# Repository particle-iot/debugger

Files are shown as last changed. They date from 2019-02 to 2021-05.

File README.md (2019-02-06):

# Particle debugger

**Design files for the CMSIS-DAP debugger**

The Particle Debugger gives you the power of professional debugging at a fraction of the cost. Using this accessory, you’ll be able to program Particle mesh-ready hardware over common interfaces like JTAG and SWD, using open source tools like GDB and openocd.

Supports the open source [CMSIS-DAP specification](https://os.mbed.com/handbook/DAPLink) and DAPLink firmware developed by ARM. On Mac, Linux, and Windows it requires no additional device drivers. 

It also provides a USB to TTL serial port. This requires no device drivers on Mac, Linux, or Windows 10 or later, but you may need to [install a device driver](https://os.mbed.com/docs/v5.9/tutorials/windows-serial-driver.html) for earlier versions of Windows to use the serial port feature.

Comes with one JTAG ribbon cable.

For more information about debugging see the [JTAG FAQ](https://docs.particle.io/support/particle-tools-faq/jtag/). Future version of Particle Workbench will support the Particle Debugger as well.

### Debugging mesh devices

Connecting a Argon, Boron, or Xenon to the debugger is as easy as connecting the included ribbon cable, as pictured below. It's keyed so it will only go in one way. The devices ship with a small plastic protective plug in the debugging connector; make sure you remove that first.

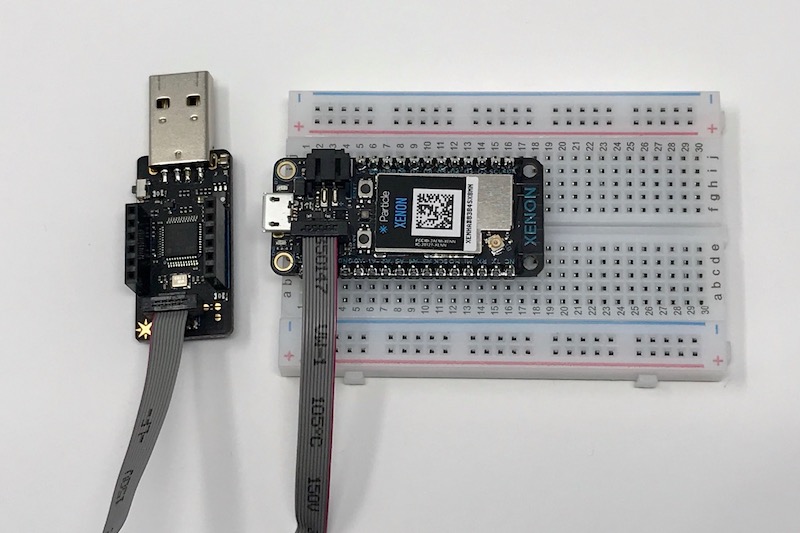
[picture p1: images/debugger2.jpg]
Debugger


### Debugging legacy platforms

Using the headers on the Particle Debugger you can attach it to other ARM processor devices like the STM32 in the Particle Photon, P1, Electron, and E Series for SWD (serial wire debug).

With the debugger positioned like this, USB connector toward you and the headers facing up:

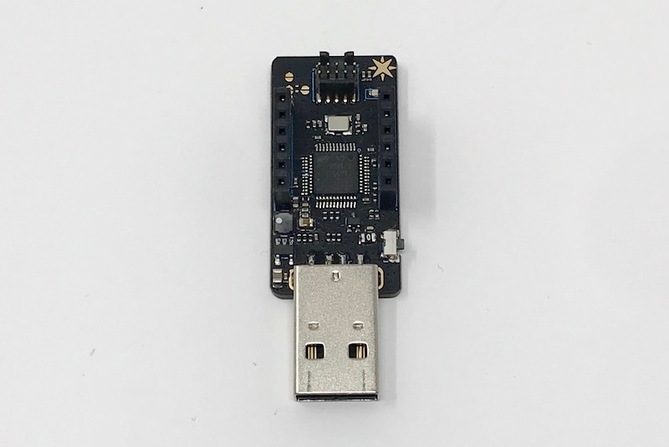
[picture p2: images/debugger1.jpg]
Debugger


| Left Header | Right Header |
| --- | ----- |
| VDD | SWCLK |
| RTS | SWDIO |
| RX  | NC |
| TX  | NC |  
| CTS | GND | 
| GND | VUSB  |

In order to use SWD debugging you need to connect:

- D7: SWDIO
- D6: SWCLK
- GND

## Connector

If you want to include the 5x2 micro JTAG connector on your own board a connector compatible with this one works:
 
- Connector Header Surface Mount 10 position 5x2 0.050" (1.27mm)
- [Samtec FTSH-105-01-F-DV-K](https://www.digikey.com/product-detail/en/FTSH-105-01-F-DV-K/SAM8796-ND/2649974)

In the connector directory is:

- JTAGConn.lbr, an Eagle CAD library file containing this connector footprint, symbol, and device. The device has all of the pins labeled for easy use.
- JTAGTest1.brd and .sch. This is just a simple breakout and is what I used to test the footprint. It works.

## Firmware Update

To update the interface firmware with the latest version:

1. Download the latest interface firmware from the firmware directory, above.
2. Press and hold the button on the Debugger.
3. Plug into an USB port of your PC.
4. It will show up a `MAINTENANCE` drive/volume.
5. Drag and drop the firmware to the drive/volume.
6. After that, it will be unmounted and remounted automatically and showing a `DAPLink` drive/volume.
7. Now, you can drag and drop any nRF52840 firmware into the `DAPLink` drive/volume to test.

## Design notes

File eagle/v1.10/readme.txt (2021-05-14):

2021/5/7
1.change U$1 to be closed so the RESET pin is actually connected to the debug port.
2.expose SWO and /RESET on the 2 empty breakout header pins.

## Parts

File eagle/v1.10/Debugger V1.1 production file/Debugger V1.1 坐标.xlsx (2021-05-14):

Name | X | Y | Degree | value | package
C1 | 4.41 | 13.75 | 180 | 0.1uF | C0402
C2 | 5.24 | 21.46 | 0 | 0.1uF | C0402
C3 | 4.41 | 24.86 | 270 | 0.1uF | C0402
C4 | -2.2 | 25.57 | 90 | 20pF | C0402
C5 | 3.4 | 26.55 | 270 | 20pF | C0402
C6 | -3.08 | 25.54 | 90 | 0.1uF | C0402
C7 | -2.55 | 23.45 | 180 | 0.1uF | C0402
C8 | -5.82 | 16.67 | 90 | 0.1uF | C0402
C9 | -4.04 | 10.06 | 0 | 22uF | C0805
C10 | -8.41 | 2.11 | 270 | 22uF | C0805
C11 | -4.43 | 12.22 | 0 | 0.1uF | C0402
C12 | -7.24 | 2.24 | 270 | 0.1uF | C0402
C13 | -4.39 | 11.35 | 0 | 470pF | C0402
C14 | -2.72 | 8.05 | 270 | 0.1uF | C0402
C15 | -4.42 | 13.11 | 0 | 1nF | C0402
C16 | 4.24 | 33.34 | 270 | 0.1uF | C0402
C17 | 5.12 | 33.35 | 270 | 0.1uF | C0402
C18 | 4.95 | 9.37 | 180 | 1nF | C0402
DEBUG_OUT | 0.13 | 32.07 | 180 | CON5X2 | CON5X2_1.27
F1 | 4.61 | 7.83 | 180 | ASMD0805-100 | F0805
F2 | -7.39 | 29.36 | 0 | ASMD0805-100 | F0805
K1 | 7.9 | 6.73 | 270 | K2-1806SQ | K2-1806C
L1 | -7.37 | 10.26 | 0 | NR3015T2R2M | INDUCTOR-NR3015
L2 | -5.84 | 13.36 | 90 | GZ1608D300TF | R-0603A
LED1 | 6.07 | 30.51 | 0 | LEDLED-0603 | LED-0603
Q1 | 2.57 | 10.4 | 0 | S9013W | SOT-323
R1 | -4.37 | 13.98 | 0 | 100R | R-0402S
R2 | -0.61 | 11.45 | 90 | 100R | R-0402S
R3 | -1.51 | 11.45 | 270 | 100R | R-0402S
R4 | 3.4 | 24.86 | 90 | 10K | R-0402S
R5 | -3.98 | 25.54 | 90 | 10K | R-0402S
R6 | 5.72 | 19.45 | 270 | 4.7K | R-0402S
R7 | -0.32 | 8.1 | 90 | 0R | R-0402S
R8 | 0.54 | 8.09 | 270 | 0R | R-0402S
R9 | 5.12 | 11.64 | 90 | 36K | R-0402S
R10 | 5.99 | 11.65 | 90 | 10K | R-0402S
R11 | -1.22 | 8.09 | 90 | 1.5K | R-0402S
R12 | 5.76 | 13.91 | 90 | 100R | R-0402S
R15 | 0.25 | 11.45 | 90 | 100R | R-0402S
R16 | 5.74 | 15.87 | 90 | 1K | R-0402S
R17 | -5.63 | 31.29 | 270 | 100R | R-0402S
R18 | -5.33 | 8.08 | 90 | 560K | R-0402S
R19 | -4.5 | 8.08 | 270 | 124K | R-0402S
R20 | -3.66 | 8.05 | 270 | 10K | R-0402S
U1 | 0 | 17.83 | 270 | GD32F103CBT6 | LQFP-48-7X7
U2 | -7.42 | 6.07 | 180 | SY8088AAC | SOT23-5L
USB1 | -0.01 | 4.37 | 0 | USB_PCB | USB_PCB
Y1 | 0.51 | 25.59 | 0 | 16Mhz 9PF | CRY_3225_SMT

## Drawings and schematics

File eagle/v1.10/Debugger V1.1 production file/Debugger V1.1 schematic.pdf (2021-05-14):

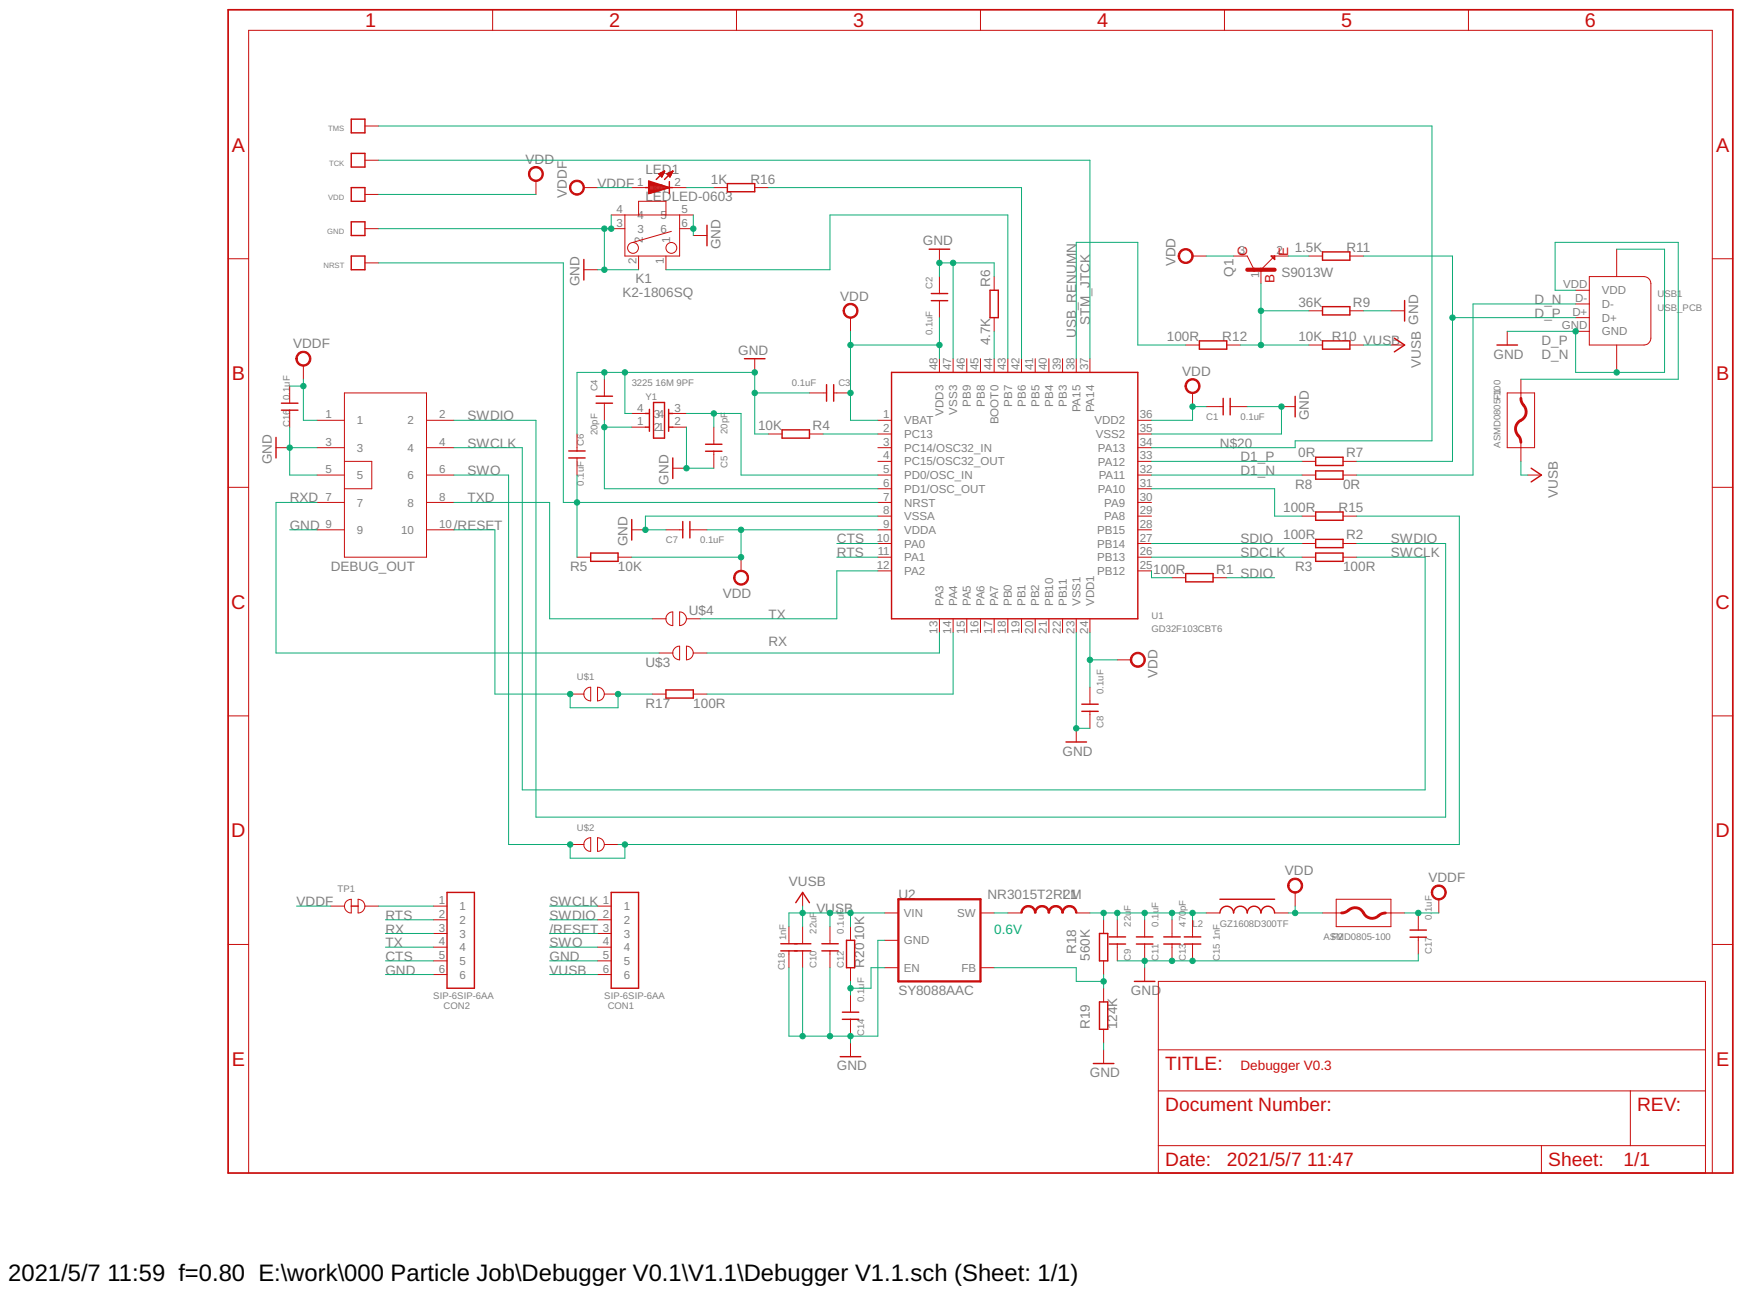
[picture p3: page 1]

2 LED1

2021/5/7 11:59 f=0.80 E:\work\000 Particle Job\Debugger V0.1\V1.1\Debugger V1.1.sch (Sheet: 1/1)

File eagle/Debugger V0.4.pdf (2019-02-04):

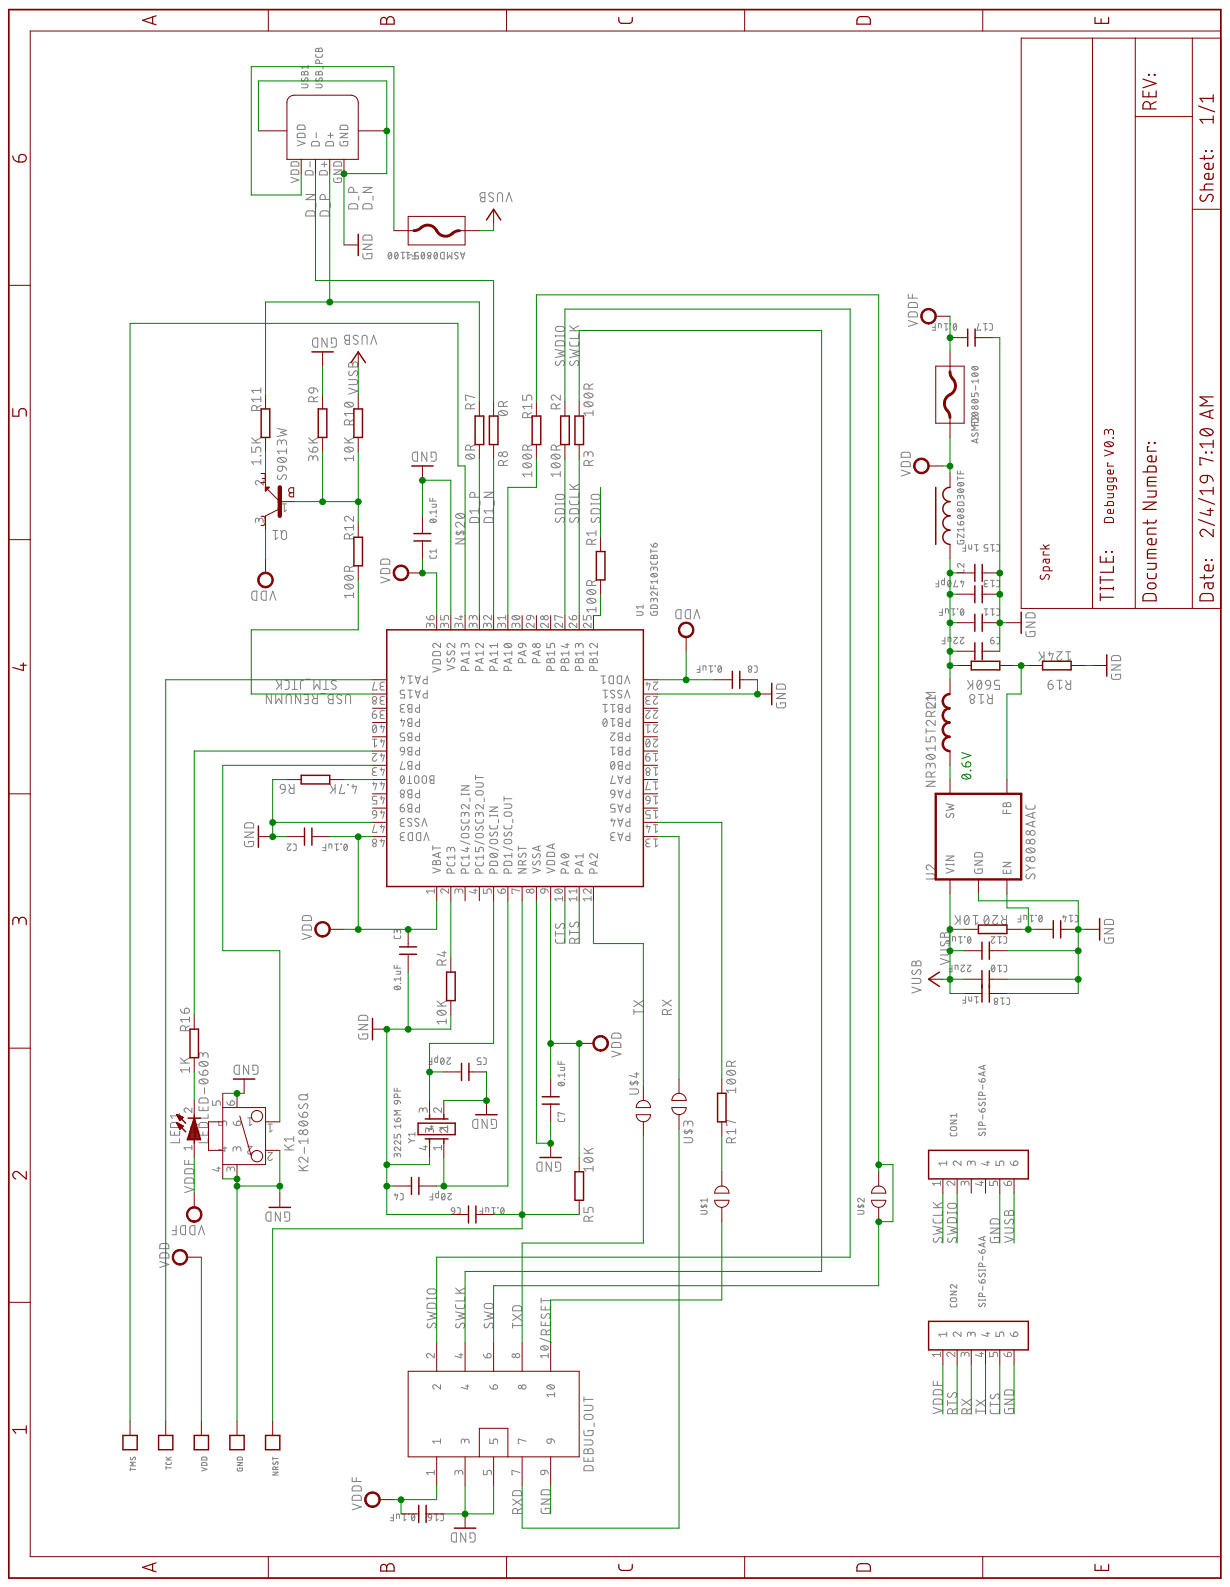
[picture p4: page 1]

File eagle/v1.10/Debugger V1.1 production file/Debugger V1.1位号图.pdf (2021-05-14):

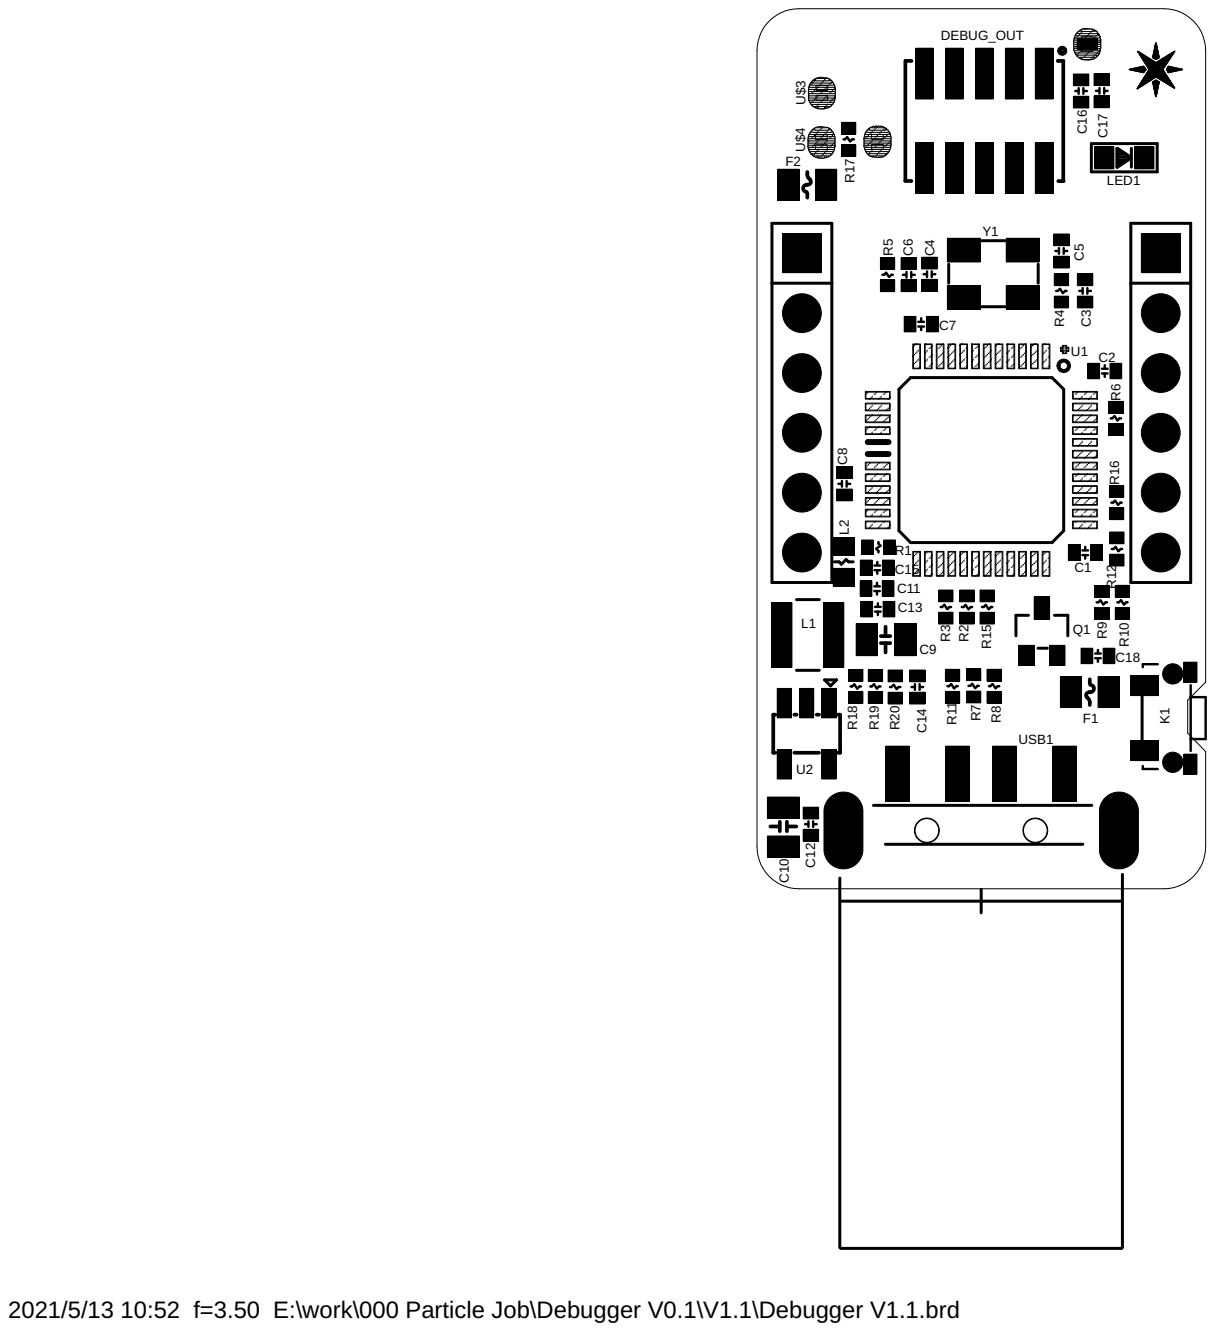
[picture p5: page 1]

2021/5/13 10:52 f=3.50 E:\work\000 Particle Job\Debugger V0.1\V1.1\Debugger V1.1.brd

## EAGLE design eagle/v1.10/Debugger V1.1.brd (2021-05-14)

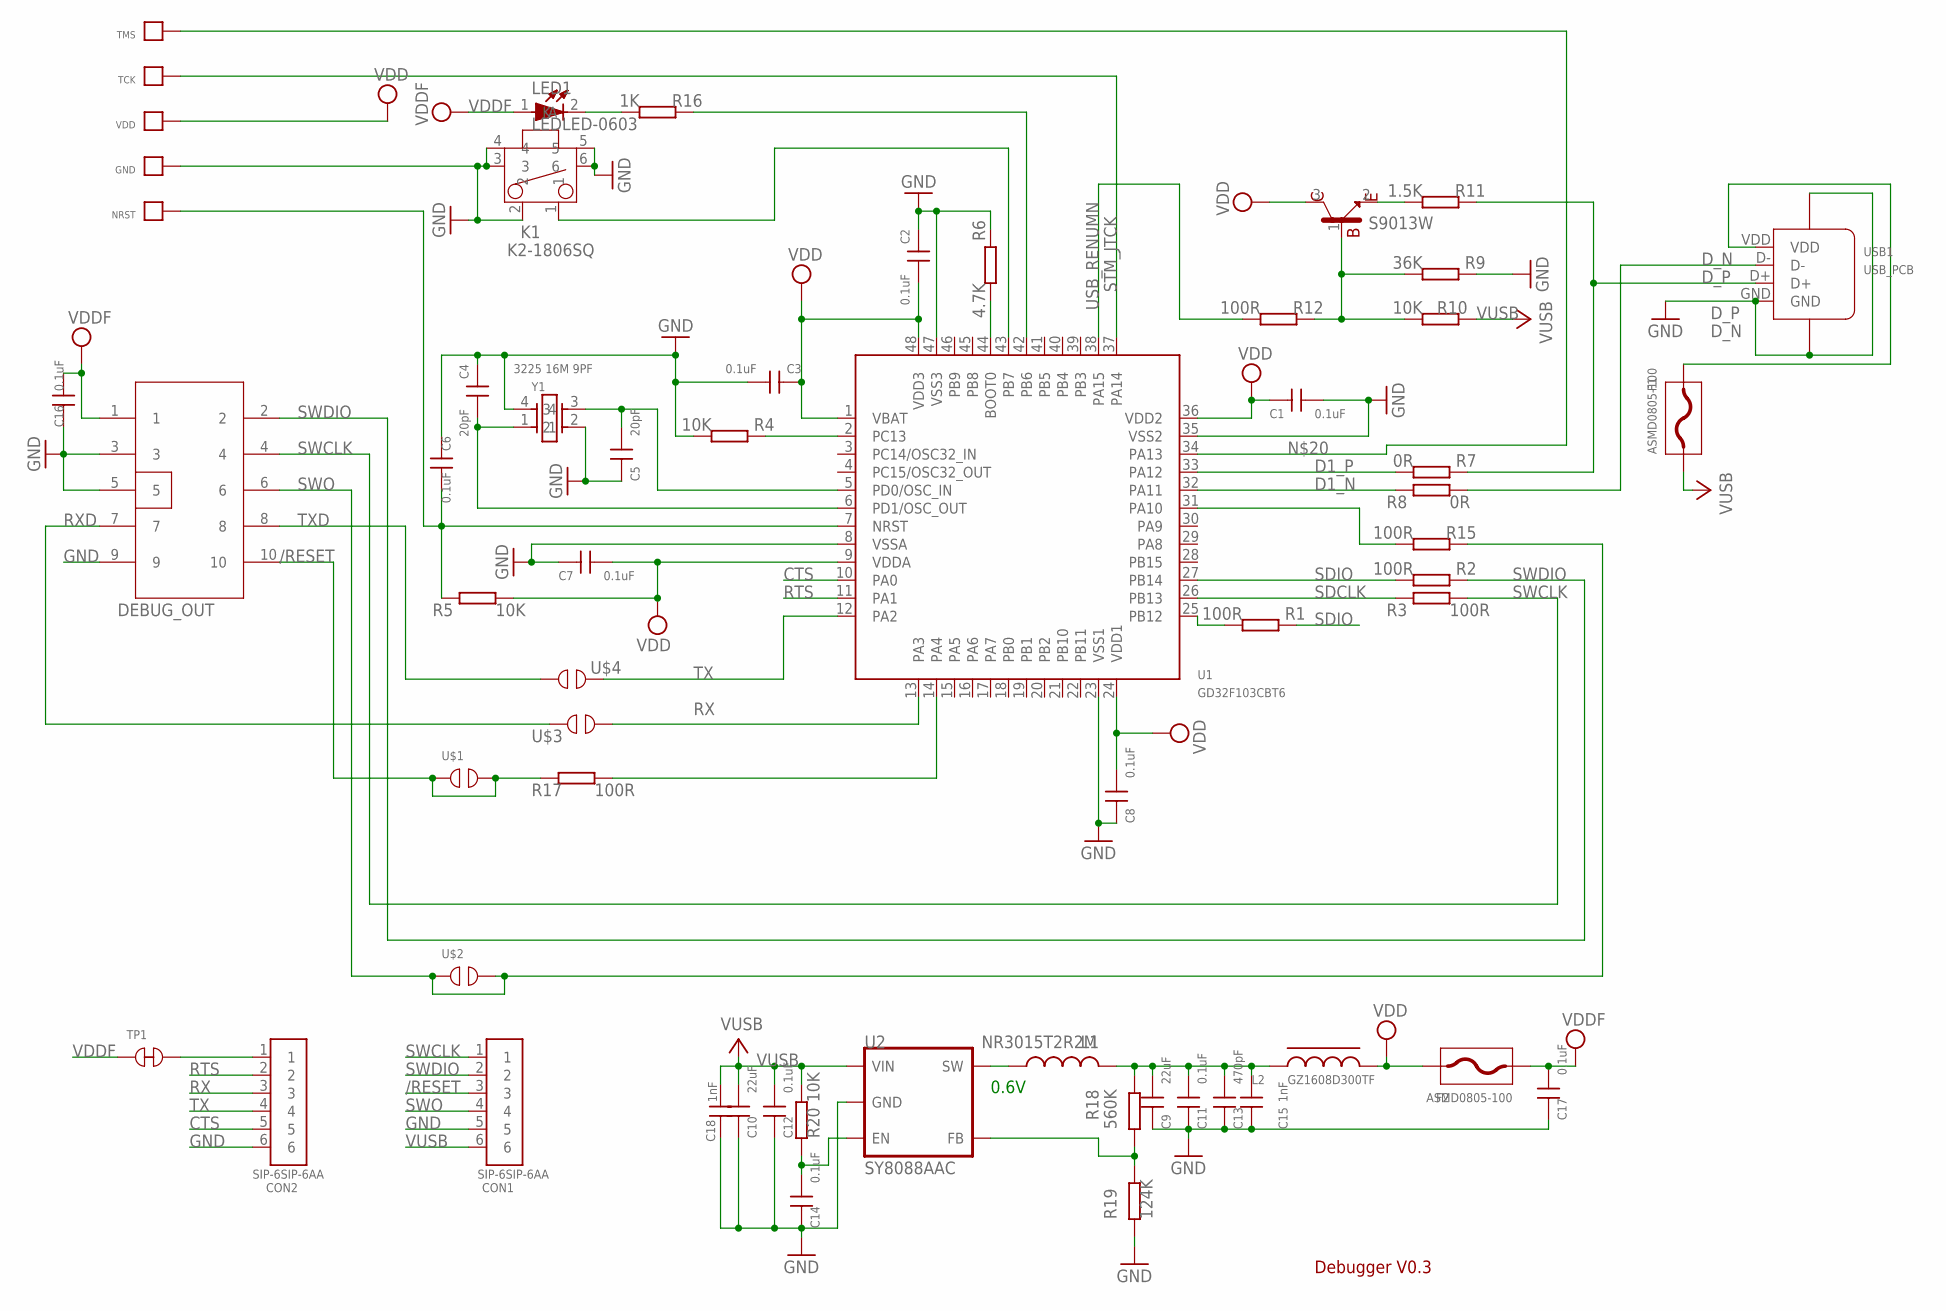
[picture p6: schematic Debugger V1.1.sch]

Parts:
C1, C2, C3, C6, C7, C8, C11, C12, C14, C16, C17: 0.1uF; C0402
C4, C5: 20pF; C0402
C9, C10: 22uF; C0805
C13: 470pF; C0402
C15, C18: 1nF; C0402
CON1, CON2: SIP-6SIP-6AA; PAIZHEN6P_2.54AA
DEBUG_OUT: CON5X2; CON5X2_1.27
F1, F2: ASMD0805-100; F0805
GND: TPTP; TP
K1: K2-1806SQ; K2-1806C
L1: NR3015T2R2M; INDUCTOR-NR3015
L2: GZ1608D300TF; R-0603A
LED1: LEDLED-0603; LED-0603
NRST: TPTP; TP
Q1: S9013W; SOT-323
R1, R2, R3, R12, R15, R17: 100R; R-0402S
R4, R5, R10, R20: 10K; R-0402S
R6: 4.7K; R-0402S
R7, R8: 0R; R-0402S
R9: 36K; R-0402S
R11: 1.5K; R-0402S
R16: 1K; R-0402S
R18: 560K; R-0402S
R19: 124K; R-0402S
TCK: TPTP; TP
TMS: TPTP; TP
TP1: TP_SHORT
U1: GD32F103CBT6; LQFP-48-7X7
U2: SY8088AAC; SOT23-5L
U$1, U$2, U$3, U$4: TP_OPEN
USB1: USB_PCB
VDD: TPTP; TP
Y1: 3225 16M 9PF; CRY_3225_SMT

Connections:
/RESET: CON1.3, DEBUG_OUT.10, R17.1, U$1.1, U$1.2
CTS: CON2.5, U1.10 (PA0)
D1_N: R8.1, U1.32 (PA11)
D1_P: R7.2, U1.33 (PA12)
D_N: R8.2, USB1.D-
D_P: R7.1, R11.1, USB1.D+
GND: C1.1, C2.2, C3.1, C4.2, C5.2, C6.2, C7.2, C8.2, C9.2, C10.2, C11.2, C12.2, C13.2, C14.2, C15.2, C16.2, C17.2, C18.2, CON1.5, CON2.6, DEBUG_OUT.3, DEBUG_OUT.5, DEBUG_OUT.9, GND.P$1, K1.2, K1.3, K1.4, K1.5, K1.6, R4.2, R6.1, R9.1, R19.1, U1.8 (VSSA), U1.23 (VSS1), U1.35 (VSS2), U1.47 (VSS3), U2.2 (GND), USB1.GND, USB1.GND1, USB1.GND2, Y1.2, Y1.4
unnamed: R1.2, U1.25 (PB12)
unnamed: C6.1, NRST.P$1, R5.1, U1.7 (NRST)
unnamed: R4.1, U1.2 (PC13)
unnamed: C5.1, U1.5 (PD0/OSC_IN), Y1.3
unnamed: C4.1, U1.6 (PD1/OSC_OUT), Y1.1
unnamed: Q1.1 (B), R9.2, R10.2, R12.1
unnamed: R15.2, U1.31 (PA10)
unnamed: Q1.2 (E), R11.2
unnamed: R6.2, U1.44 (BOOT0)
unnamed: LED1.2 (K), R16.2
unnamed: F1.P$2 (2), USB1.VDD
unnamed: K1.1, U1.43 (PB7)
unnamed: R16.1, U1.42 (PB6)
unnamed: L1.1, U2.3 (SW)
unnamed: R17.2, U1.14 (PA4)
unnamed: TMS.P$1, U1.34 (PA13)
unnamed: R18.1, R19.2, U2.5 (FB)
unnamed: C14.1, R20.1, U2.1 (EN)
unnamed: C9.1, C11.1, C13.1, C15.1, L1.2, L2.1, R18.2
RTS: CON2.2, U1.11 (PA1)
RX: CON2.3, U1.13 (PA3), U$3.2
RXD: DEBUG_OUT.7, U$3.1
SDCLK: R3.1, U1.26 (PB13)
SDIO: R1.1, R2.2, U1.27 (PB14)
STM_JTCK: TCK.P$1, U1.37 (PA14)
SWCLK: CON1.1, DEBUG_OUT.4, R3.2
SWDIO: CON1.2, DEBUG_OUT.2, R2.1
SWO: CON1.4, DEBUG_OUT.6, R15.1, U$2.1, U$2.2
TX: CON2.4, U1.12 (PA2), U$4.1
TXD: DEBUG_OUT.8, U$4.2
USB_RENUMN: R12.2, U1.38 (PA15)
VDD: C1.2, C2.1, C3.2, C7.1, C8.1, F2.P$2 (2), L2.2, Q1.3 (C), R5.2, U1.1 (VBAT), U1.9 (VDDA), U1.24 (VDD1), U1.36 (VDD2), U1.48 (VDD3), VDD.P$1
VDDF: C16.1, C17.1, CON2.1, DEBUG_OUT.1, F2.P$1 (1), LED1.1 (A), TP1.1, TP1.2
VUSB: C10.1, C12.1, C18.1, CON1.6, F1.P$1 (1), R10.1, R20.2, U2.4 (VIN)

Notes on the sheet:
0.6V
Debugger V0.3

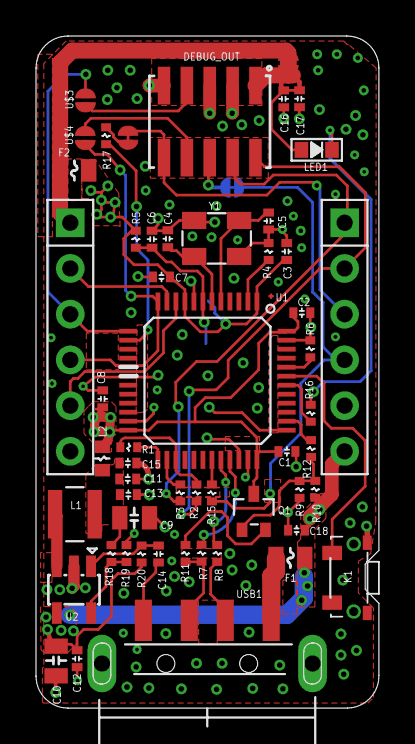
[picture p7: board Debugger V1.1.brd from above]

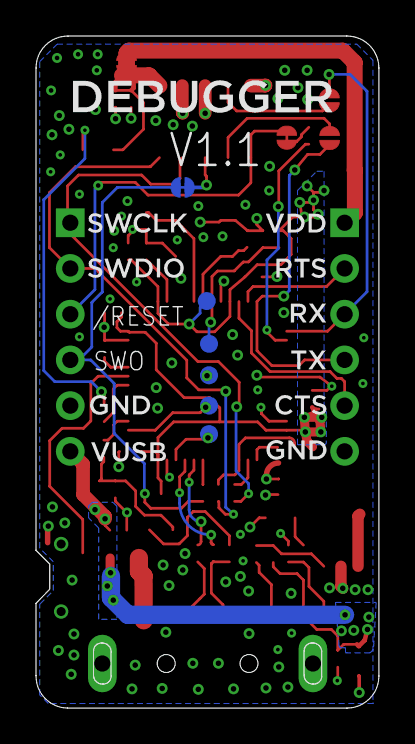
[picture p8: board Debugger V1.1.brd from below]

Board: 2 copper layers, 19.0 x 37.3 mm, 62 parts (7 on the bottom side), 41 nets.

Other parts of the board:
U$5, U$6: SPARK_LOGO2

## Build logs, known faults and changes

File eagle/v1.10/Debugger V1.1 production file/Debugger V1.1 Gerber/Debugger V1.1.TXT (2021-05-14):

%
M48
M72
T01C0.00787
T02C0.00800
T03C0.01000
T04C0.01200
T05C0.01969
T06C0.03543
T07C0.03937
%
T01
X67150Y187713
T02
X72550Y182313
X74650Y178613
X68350Y173713
X60950Y162013
X59150Y168913
X56750Y166013
X55850Y154513
X61650Y150813
X68350Y142513
X48650Y111813
X46450Y108413
X44350Y110713
X34650Y103713
X33150Y99313
X32550Y93513
X31350Y108213
X24350Y99513
X21950Y77713
X24950Y74113
X11950Y67313
X28650Y127113
X29350Y130913
X27350Y144013
X13150Y131713
X6350Y132313
X6150Y142313
X46950Y163713
T03
X42350Y171113
X41250Y164313
X37050Y164513
X32050Y171413
X26850Y174513
X54050Y108213
X57950Y104113
X39550Y99213
X60750Y165713
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

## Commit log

2019-02-04 Public release
    [Debugger V0.4.sch]
2019-02-04 Add missing brd and pdf
    [Debugger V0.4.brd]
2019-02-06 Add connector info
    [JTAGTest1.brd, JTAGTest1.sch]
2021-05-14 create V1.1 file
    [Debugger V1.1 坐标.xlsx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]
